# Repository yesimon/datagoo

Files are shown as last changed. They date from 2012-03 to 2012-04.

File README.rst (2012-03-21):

=======
Datagoo
=======

Project Description
===================

DataGoo is an open-source device designed to measure power generation
or consumption from small-scale electrical installations--cheaply. We
designed it to be initially deployed in `microhydro plants
<http://www.alterna-la.org/en/projects/microhydro>`_ run by `Alterna
<http://www.alterna-la.org/en>`_ in Guatemala.

DataGoo builds heavily on a similar, open-source device called the
`OpenEnergyMonitor <http://www.openenergymonitor.org>`_ (emon). The emon system
involves a transmitting device, a receiving device, and
display software and is targeted for in-home deployment. Our device is
designed for deployment in the field, so it uses a simpler output
interface: text messages over GSM and logging to an SD card.

Software Development
====================

Building with Arduino IDE
-------------------------

Download the required external libraries (see http://datagoo.readthedocs.org)
and place them in the Arduino ``libraries/`` directory. Open
``datagoo.ino``, compile and upload using the GUI.

Building With CMake
-------------------

**OS X/Linux**

To build on *nix systems (tested on OS X 10.7)::

   ./configure
   cd build
   make

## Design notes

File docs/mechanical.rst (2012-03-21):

.. _ref-mechanical:

==========
Mechanical
==========

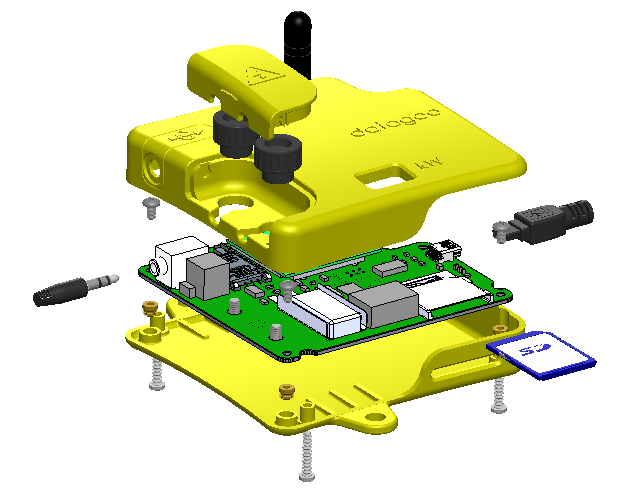
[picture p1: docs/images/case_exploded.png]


3D Printing the Datagoo Case
============================

The files below can be sent to any 3D printing company for
fabrication. I would suggest Shapeways, for price. Our first prototype
was completed by ZoomRP. Use these links to order your own copy:

| **Shapeways Permalinks**
| Upper Case: http://shpws.me/4lcv $33.74
| Lower Case: http://shpws.me/4lcx $37.51
| Cover: http://shpws.me/4ldY $6.22

The three files that constitute the case are the Cover, the Lower Body
and the Upper Body. The .stl (stereolithography) file is used by most
common 3d printing companies.

If there are needed changes to the solid files, the original
Solidworks files still exist. Please email nhallsny@stanford.edu with
any requests.

Known Errors
============

No known errors.

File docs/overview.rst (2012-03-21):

.. _ref-overview:

================
Project Overview
================

.. _ref-overview_mission:

Alterna's Mission
==================

Alterna on their mission:

   Alterna is a Center for Innovation and Entrepreneurship based in
   Quetzaltenango, Guatemala. Our mission is to develop technologies
   and build local businesses that satisfy basic needs and provide
   economic growth opportunities for the Guatemalan people in an
   environmentally sustainable way.

One of their major projects are micro-hydro plants in rural areas:

   Two million Guatemalans live without access to electricity. The vast
   majority of these people live in rural areas. Expansion of the
   national grid to the areas that are left unserved is increasingly
   difficult due to geographic constraints.

   Guatemala is also a country with great potential for utilization of
   hydroelectric power. The extensive rainfall and mountainous terrain of
   the country provide optimal conditions for generating electricity with
   water power.

| http://www.alterna-la.org/en
| http://www.alterna-la.org/en/projects/microhydro

Our Mission
============

Alterna currently has no good ways to monitor how much power these
micro-hydro plants produce, because off-the-shelf systems designed for
ultra-high current environments are expensive. Measuring power
generation is useful both to understand the efficacy of these
installations and because it is prerequisite to applying for carbon
grants which can offset the costs of development. Therefore, we
prototyped a circuit based on the open-source Arduino platform which
measures single-phase AC power coming out of the installation, logs it
to an SD card, and transmits daily SMS status updates over a GSM
network. The circuit can handle household voltages (~240V), currents
up to 100A, and costs around $200 (and as little as $100 when produced
at scale).

Carbon Offsets
---------------

Becoming accredited to sell carbon offsets is not a trivial process
and having information on kWh generated is only one part of it.
Nevertheless, organizations like `ClimateTrust
<http://www.climatetrust.org/>`_ exist to help organizations through
the bureaucratic steps of the process, but they can't do anything
without data, so we feel confident that this device will be an
important part of offsetting micro-hydro costs with carbon offsets.

The U.S. Department of Energy Clean Energy Application Center authored
a report on selling carbon offsets, which you can read `here
<http://www.chpcenternw.org/NwChpDocs/SellingCarbonOffsets.pdf>`_.

Specs In More Detail
---------------------

**Intended Purpose**

* Easy to use power measurement device
* Cheap to make
* Able to monitor current and voltage on 1 phase system
* Logs data to an SD card
* GSM connectivity provides two functionality:
* Sends an SMS if the voltage drops for an extended period
* Sends a daily "power collected" SMS with the power generated during
  that day
* Flexible design allows for reprogramming and hacking

**Intended Users**

* Engineering graduates and other workers with basic technology fluency.
* Designed so that it can be manufactured *relatively* easily.

**Power Measurement Specifications**

* Nominal voltage is 220V. Maximum we've seen was 225, minimum 219.
  There may be brief moments (around half a second or less) when it is
  much lower, down to 150V, when an extra heavy load is switched on.
* Nominal frequency is 60 Hz. Minimum 59, maximum 62.5.
* Single Phase AC.
* Current varies significantly depending on the season (water flow).
  Max in the rainy season is approximately 55A. Right now it's about
  30A. Dry season production may drop down as low as 15A, but we
  aren't sure on that yet.

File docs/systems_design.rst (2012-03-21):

.. _ref-systems_design:

==============
Systems Design
==============

Electrical Block Diagram
========================

Datagoo is built around the ATMEGA328P, the same processor used by many hobbyists for a variety of `Arduino <http://www.arduino.cc/>`_ designs. When coupled with an FTDI FT232RL USB-Serial circuit, the board can be programmed with any computer with a USB port. Other design decisions were made in the interest of cost and simplicty. Surface mount components were chosen for ease of manufacturing. The voltage and current measurement circuits were designed to utilize the ATMEGA328P's internal Analog-to-Digital converters, again reducing the component cost. The cell phone module was chosen for price - it is one of the cheapest GSM modules available. Also, all the components for which critical software needed to be written are avaiable in Arduino shield form, making testing custom applications more accessible.

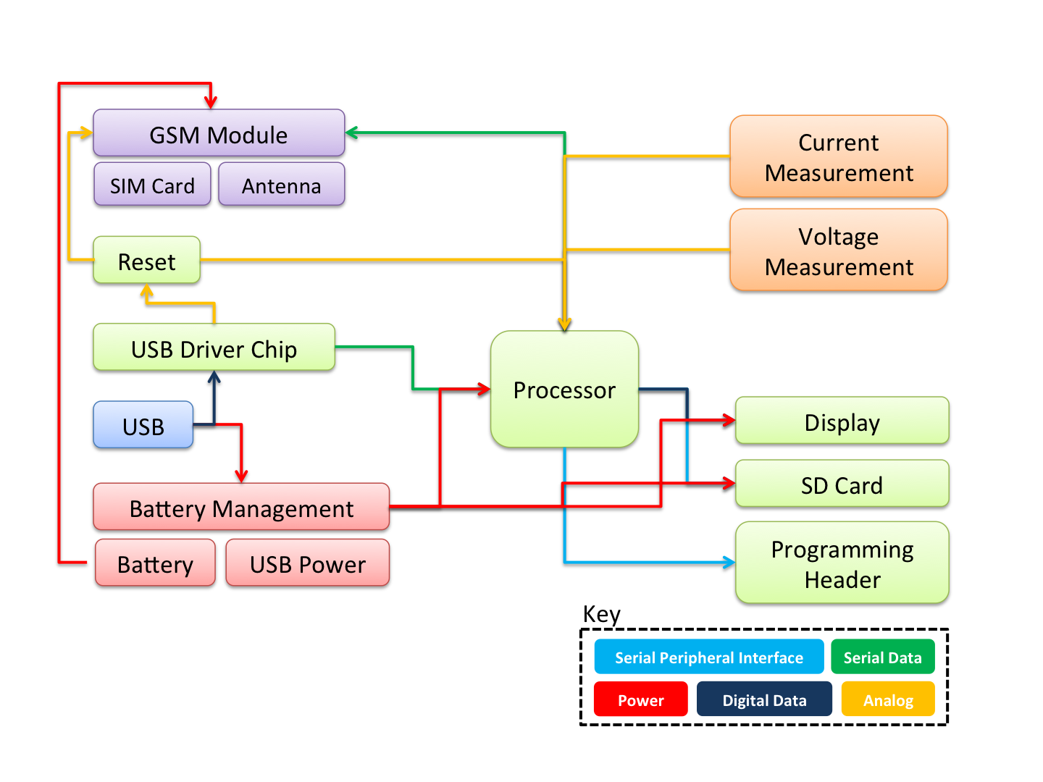
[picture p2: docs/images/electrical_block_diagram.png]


Component Locations
========================
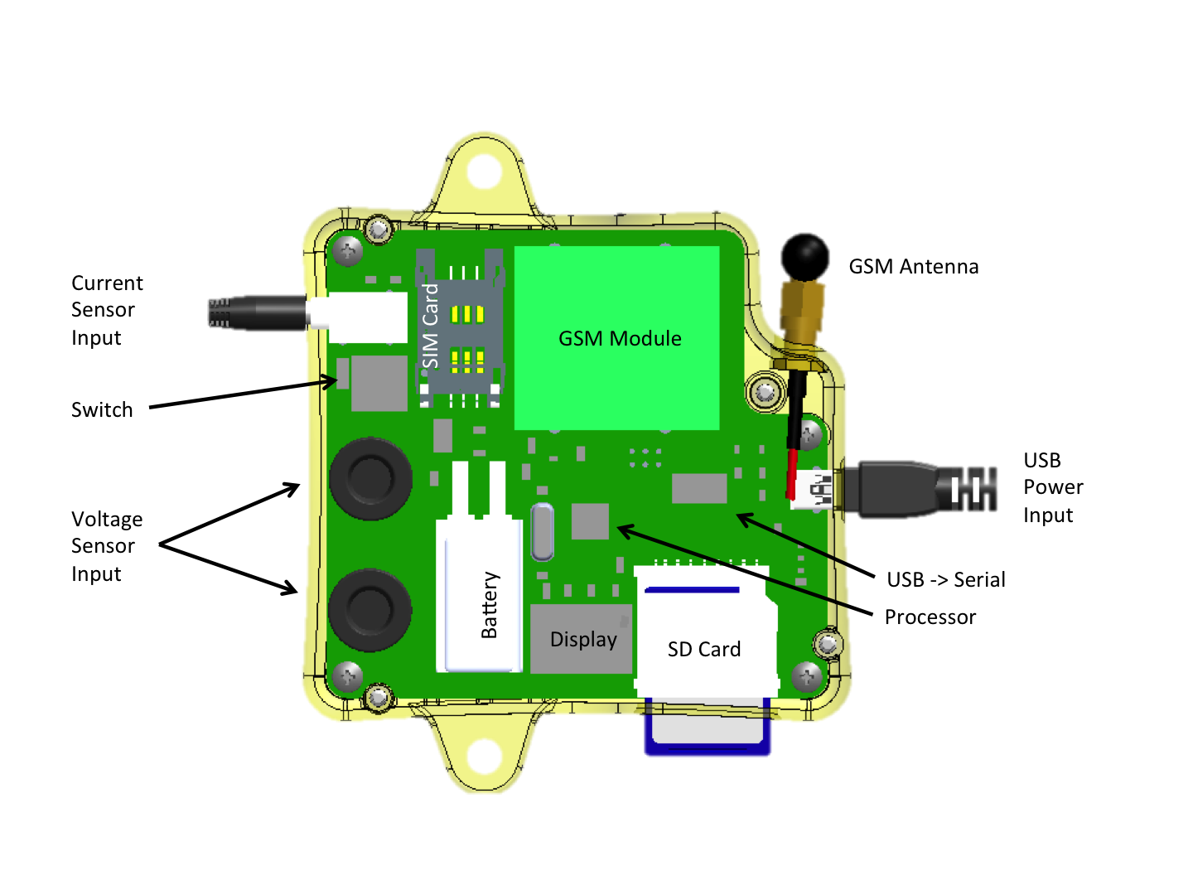
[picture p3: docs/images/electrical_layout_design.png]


Voltage Measurement System
==========================
The input voltage is rectified with a bridge rectifier. Then, a voltage divider reduces the voltage by a factor of 110. Then, the now 3.3V signal is run through an op-amp buffer for measurement accuracy. Finally, the signal is fed into the ATMEGA328P's Analog Input 1.

Current Measurement System
==========================
The Datagoo uses a "current transformer" to convert an AC signal into a readable value. A current transformer simply divides the current down. For our current transformer, a current of 100A will result in an output current of 33mA. The current is driven across a small resistor (33 ohms) to generate a voltage, which is then referenced against 1/2 * 3.3V, so both positive and negative currents can be sensed. The signal is then fed into the ATMEGA328P's Analog Input 0.

Battery Backup System
=====================
Datagoo uses a small lithium backup battery to keep the device on in the event of a power interruption. The battery is normally charged by the USB charger, and should be nominally at 4.2V. If the USB power is disconnected, the device switches to battery power and should last for ~30 minutes.

Display System
==============
The display is a two digit, seven segment display that is used to show the amount of kilo-Watts currently being measured by the device. The display is multiplexed - only one segment is on at a time, hence the faint flicker.

SMS Cell System
===============
A SM5100b GSM module is used to add cell network functionality to the Datagoo. Using the account information from a SIM card, it will send status text messages to the number written down in the configuration file. Since GSM network settings are specific to the country, make sure to change the right settings in the configuration file.

SD Card System
==============
The Datagoo is capable of reading and writing files to a SD card. This is used to log the amount of power generated as well as any faults. The user must edit a configuration file in order to use the unit.

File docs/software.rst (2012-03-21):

.. _ref-software:

========
Software
========

Downloading the Firmware
=========================

DataGoo's firmware is open-source and can be downloaded from GitHub:
https://github.com/yesimon/datagoo. Feel free to send a pull request
if you want to contribute changes either to the source code or the
documentation.

For write access to the repository, please contact Simon at
sye737+github@gmail.com.

Building with Arduino IDE
=========================

Download the required external libraries (see :ref:`libraries-label`)
and place them in the Arduino ``libraries/`` directory. Open
``datagoo.ino``, compile and upload using the GUI.

.. _libraries-label:

Software Libraries
==================

External Libraries
------------------

EmonLib
^^^^^^^^

A significant portion of our code is based on the OpenEnergyMonitor
project, which is building an open source energy monitoring solution
targeted at homes in the UK/Europe (and to a lesser extent the US).
Their library does much of the heavy lifting for us in converting the
raw voltage and current inputs coming into the DataGoo device into
power measurements.

We forked their code base primarily because we needed to output our
readings over GSM and to an SD logger, rather than over a custom
(low-power) RF system which OpenEMon uses to transmit their data.

| `Open Energy Monitor website <http://openenergymonitor.org/emon/>`_
| `GitHub (up-to-date code) for the library <https://github.com/openenergymonitor/EmonLib/>`_

Cell Phone Communication
-------------------------

There isn't exactly a library for communicating with the GSM module;
instead, it presents itself as a Serial device which can read and
write messages.

| `GSM Module Documentation <http://www.sparkfun.com/products/9533>`_
| In particular, see the `AT command set <http://www.sparkfun.com/datasheets/Cellular%20Modules/CEL-09533-AT%20Command_V1%5B1%5D.0.0-1.pdf>`_.

Also, see `this tutorial
<http://tronixstuff.wordpress.com/2011/01/19/tutorial-arduino-and-gsm-cellular-part-one/>`_
for some example code using the GSM module.

Standard Arduino Libraries
---------------------------

SD Library
^^^^^^^^^^^^

The library to write text to SD cards is part of the Arduino standard
library. It lets us write to the SD card just by creating a file and
then calling file.print().

`SD Library <http://arduino.cc/en/Reference/SD/>`_

SoftwareSerial Library
^^^^^^^^^^^^^^^^^^^^^^^

This library is also part of the Arduino standard library and emulates
a Serial port over software, which is especially critical for
interfacing with the GSM module (which takes input and provides output
over Serial).

`SoftwareSerial Library <http://arduino.cc/en/Reference/SoftwareSerial/>`_

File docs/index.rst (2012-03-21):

.. DataGoo documentation master file, created by
   sphinx-quickstart on Sun Mar  4 19:27:08 2012.
   You can adapt this file completely to your liking, but it should at least
   contain the root `toctree` directive.

Datagoo Documentation
=====================

Contents:

.. toctree::
   :maxdepth: 1

   quickstart
   overview
   ac_math
   systems_design
   components
   cost
   electrical
   mechanical
   software
   team

Project Description
===================

DataGoo is an open-source device designed to measure power generation
or consumption from small-scale electrical installations--cheaply. We
designed it to be initially deployed in `microhydro plants
<http://www.alterna-la.org/en/projects/microhydro>`_ run by `Alterna
<http://www.alterna-la.org/en>`_ in Guatemala.

DataGoo builds heavily on a similar, open-source device called the
`OpenEnergyMonitor <http://www.openenergymonitor.org>`_ (emon). The emon system
involves a transmitting device, a receiving device, and
display software and is targeted for in-home deployment. Our device is
designed for deployment in the field, so it uses a simpler output
interface: text messages over GSM and logging to an SD card.

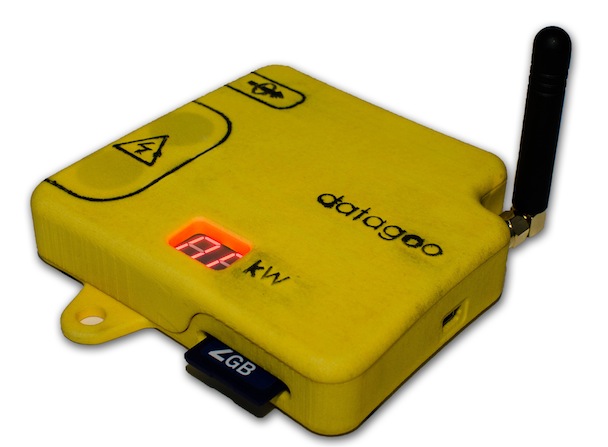
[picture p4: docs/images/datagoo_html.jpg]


Indices and tables
==================

* :ref:`genindex`
* :ref:`search`

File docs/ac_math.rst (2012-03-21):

.. _ref-ac_math:

========================
Power Measurement Theory
========================

This page covers the mathematics behind calculating real power,
apparent power, power factor, RMS voltage and RMS current from
instantaneous Voltage and Current measurements of single phase AC
electricity. Discrete time equations are detailed since the
calculations are carried out in the Arduino in the digital
domain. There are also code snippets of the equations included below:

**Real Power**

Real power (also known as active power) is defined as the
power used by a device to produce useful work.

Mathematically it is the definite integral of voltage, :math:`u(t)`,
times current, :math:`i(t)`, as follows:

.. math::

   P = \frac{1}{T} \int u(n)\times i(n) \, \mathrm{d}t

**Equation 1. Real Power Definition.**

:math:`U` - Root-Mean-Square (RMS) voltage.

:math:`I` - Root-Mean-Square (RMS) current.

:math:`cos(\varphi)` - Power factor.

The discrete time equivalent is:

.. math::

   P = \frac{1}{T} \sum_{n=0}^{N-1} u(n)\times i(n)

**Equation 2. Real Power Definition in Discrete Time.**

:math:`u(n)` - sampled instance of :math:`u(t)`

:math:`i(n)` - sampled instance of :math:`i(t)`

:math:`N` - number of samples.

Real power is calculated simply as the average of N voltage-current
products. It can be shown that this method is valid for both
sinusoidal and distorted waveforms.

Code example of equation 2::

   for (n=0; n < numberOfSamples; n++)
   {
       //instV and instI calculation from raw ADC input goes here.
       instP = instV * instI;
       sumP += instP;
   }
   realPower = sumP / numberOfSamples;

**RMS Voltage and Current Measurement**

An RMS value is defined as the square root of the mean value of the
squares of the instantaneous values of a periodically varying
quantity, averaged over one complete cycle. The discrete time equation
for calculating voltage RMS is as follows:

.. math::

   U_{rms} = \sqrt{\frac{\sum_{n=0}^{N-1} u^2(n)}{N}}

Equation 3. Voltage RMS Calculation in Discrete Time Domain.

Current RMS is calculated using the same equation, only substituting
voltage samples, :math:`u(n)`, for current samples, :math:`i(n)`.

Code example of equation 3::

   for (n=0; n < numberOfSamples; n++)
   {
       //instV calculation fsqV = instV * instV;
       sumV += sqV;
   }
   Vrms = sqrt(sumV / numberOfSamples);

Substitute V for I for current.

**Apparent Power and Power Factor**

.. math::

   P_{apparent} = V_{rms} \times I_{rms}

   cos(\varphi) = \frac{P_{real}}{P_{apparent}}

**Bringing it all together**

The following snippet carries out all the measurements above::

   for (n=0; n < numberOfSamples; n++)
   {
       //instV and instI calculation from raw ADC input goes here.
       sqV = instV * instV;
       sumV += sqV;
       sqI = instI * instI;
       sumI += sqI;
       instP = instV * instI;
       sumP +=instP;
   }
   Vrms = sqrt(sumV / numberOfSamples);
   Irms = sqrt(sumI / numberOfSamples);
   realPower = sumP / numberOfSamples;
   apparentPower = Vrms * Irms;
   powerFactor = realPower / apparentPower;

Thats it, thats the core of single phase AC power measurment
calculation.

This page is based on Atmel's AVR465 Application Note pp. 12-15 which can be
found `here <http://www.atmel.com/dyn/resources/prod_documents/doc2566.pdf>`_.

Page referenced from `OpenEnergyMonitor <http://openenergymonitor.org/emon/buildingblocks/ac-power-the-maths>`_.

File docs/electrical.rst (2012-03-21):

.. _ref-electrical:

==========
Electrical
==========

.. warning::

   Before trying to have the PCB manufactured, please contact
   nhallsny@stanford.edu for the correct settings. For components and
   designators, check out the Bill of Materials

..
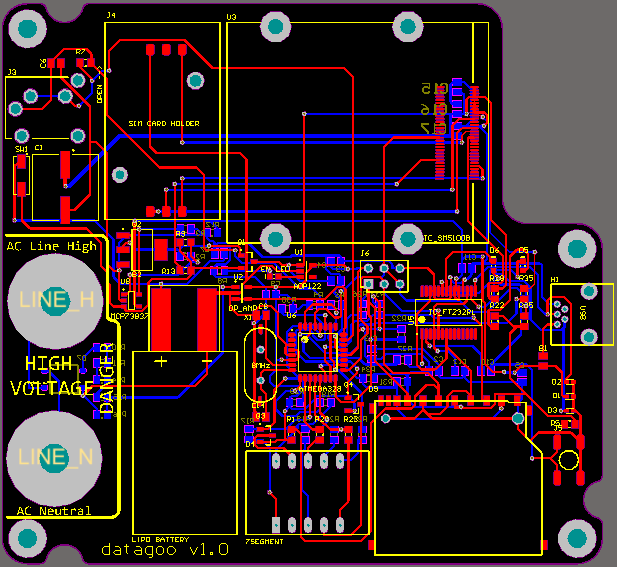
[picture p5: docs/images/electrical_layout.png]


Description
===========

For a description of how each sub-system works, consult the Systems Design

Schematic
=========

.. note::

   See below for known bugs before using these designs.

:download:`Download Electrical Schematic <images/electrical_schematic.pdf>`.

Electrical Schematics (generated in Altium):

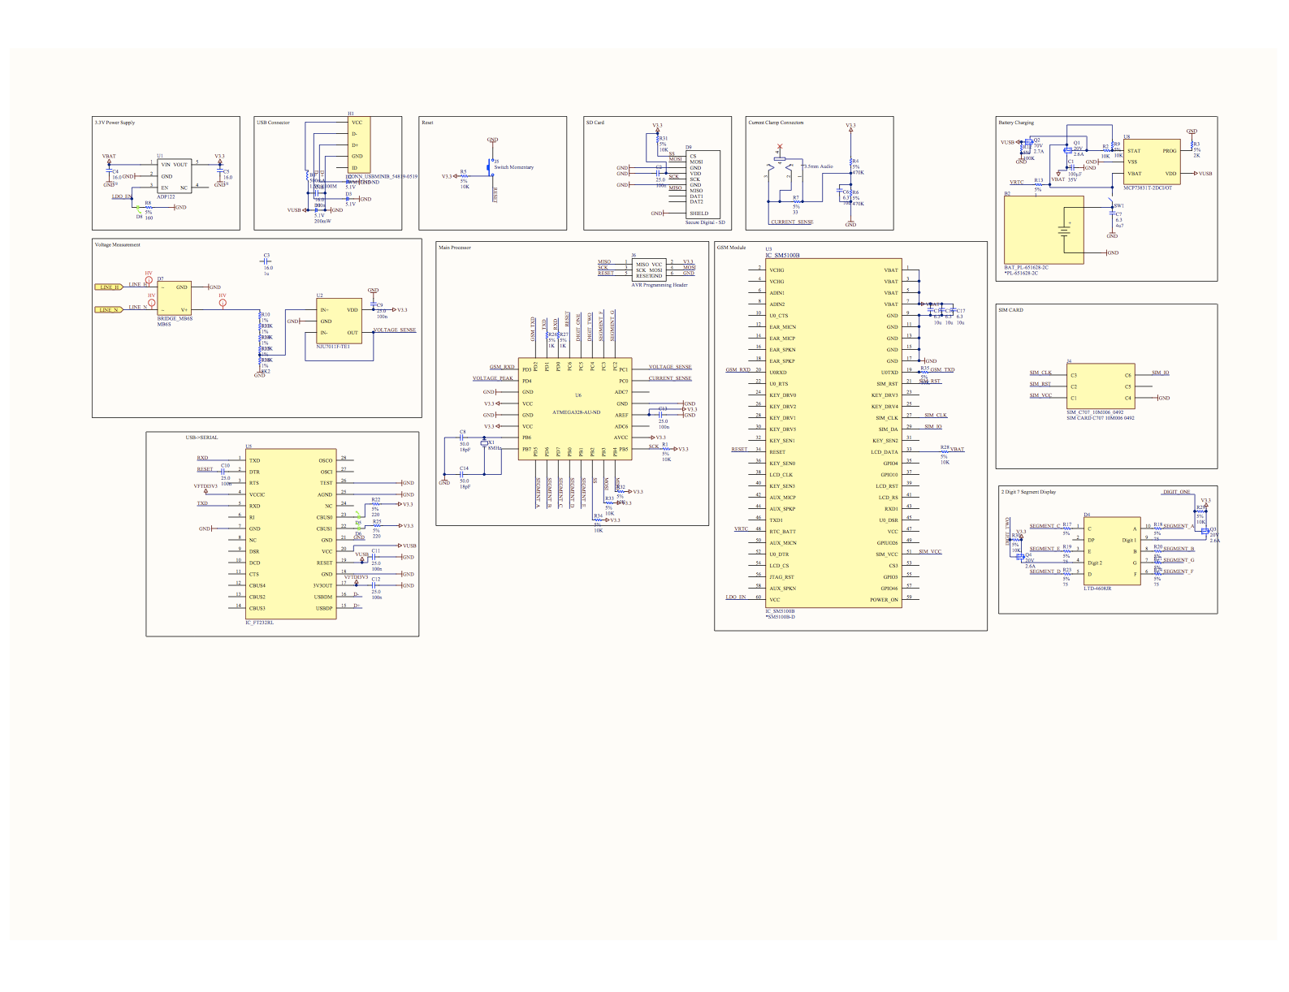
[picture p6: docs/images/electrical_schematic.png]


Design Errors
=============

1. If the device is completely discharged, and is recharged with a USB
   charger, the reset button needs to be pressed in order to reset the
   device.
2. The voltage measurement is not isolated. While we made this
   decision for cost reasons, for safety and ease of hacking the
   design should be updated with an isolation transformer.

Schematic Errors
================

There are no known errors in the below schematic.

Layout Errors
=============

There are several known errors in the layout:

1. The LDO_EN is not connected from the GSM Module
2. The GSM_TXD is not connected to the GSM Module
3. The MOSI pin on the AVR programming header is RST, and should be MOSI
4. The Zener diode footprint does not have a direction indicator
5. The LED footprint does not have a clear direction indicator
6. The footprint for SW1 is incorrect, but hackable
7. The large 100uF capacitor doesn't have a polarity marking
8. The same net is connected to two of the seven segment display pins
9. The pullup for the reset net is not connected to 3.3V

3D Layout
=========

The 3D render of the electrical layout:

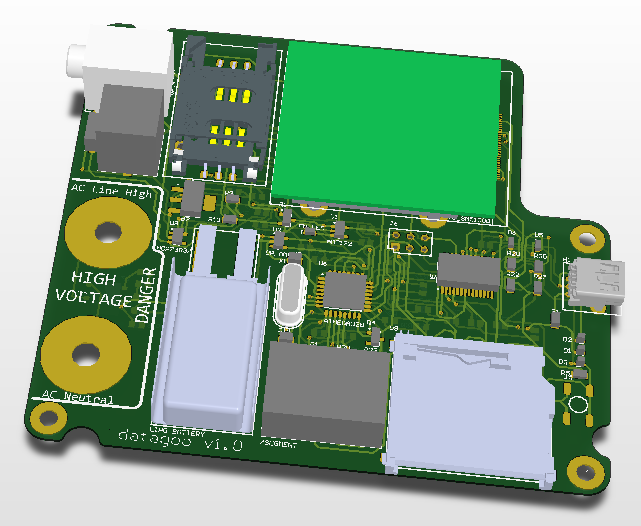
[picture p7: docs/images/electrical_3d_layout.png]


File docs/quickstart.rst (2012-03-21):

.. _ref-quickstart:

================
Quickstart Guide
================

This guide is for installing a datagoo with hardware and firmware
preinstalled. It details the steps for configuring and attaching the
datagoo to a power supply, so that it is ready to send text
notifications.

Required Materials
==================
* Datagoo
* Current clamp
* Small philips screwdriver
* USB mini-b charger
* Activated SIM card with SMS plan (minimum 50 SMS per month)
* SD Card (minimum 16 MB)
* AC measurement cord
* Screws for mounting

Installation
============

.. warning::

   Make sure that all wires are disconnected from the device before removing the cover.

#. Remove the high voltage cover (may require a small tool) and the
   two plastic knobs.

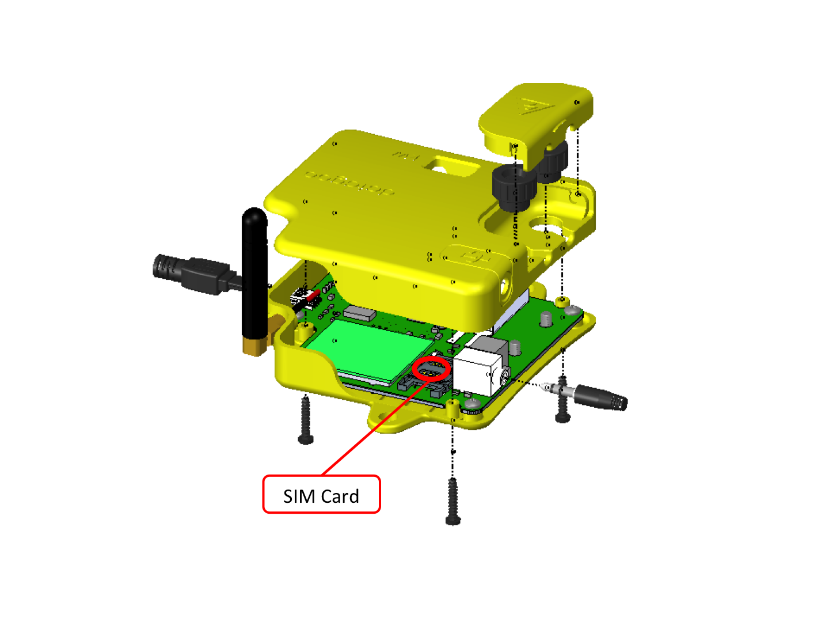
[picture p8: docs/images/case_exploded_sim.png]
   

#. Unscrew the four screws on the bottom of the device and remove the
   top case.

#. Place an activated SIM card in the SIM card holder. (Make sure that
   the SIM card is capable of sending text messages via a normal
   mobile phone before trying with the Datagoo)

#. Flip the ON/OFF switch to ON. You should see a small green light turn on.

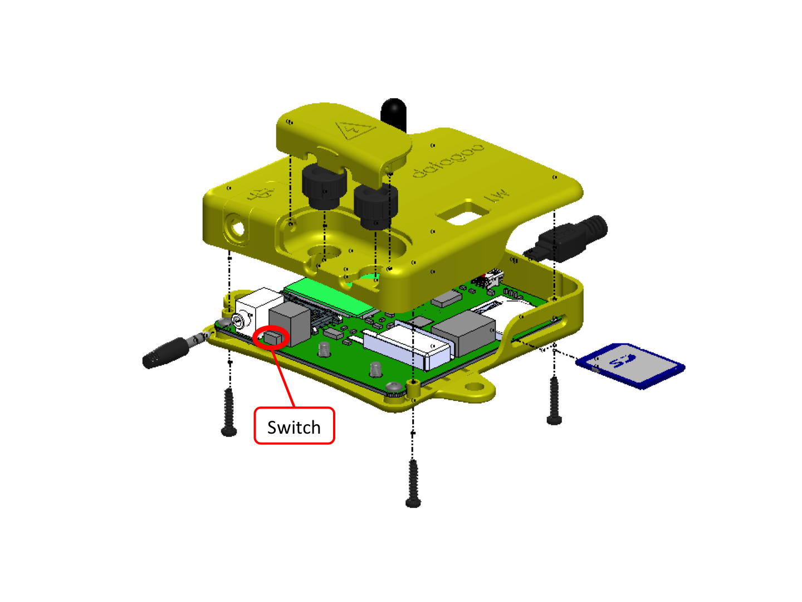
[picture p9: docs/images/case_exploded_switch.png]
   

#. Put the top back on the device and screw in the four screws. Do not
   put knobs or high voltage cover back on.

#. Format an SD card to FAT16. (This is by default for SD cards, but
   please double check).

#. Create file ``CELL.TXT`` containing the mobile number to notify of
   power usage statistics and alerts. An example ``CELL.TXT`` file::

      5731921102

#. Place the SD card in the SD slot.

#. Plug in USB charger.

   .. warning::

      The USB charger should not be a computer. Plugging in the
      computer USB charger and line voltage to the voltage terminals
      at the same time will destroy both the datagoo and your
      computer.

#. Connect current sensor. The current sensor should be clamped around
   only one wire.

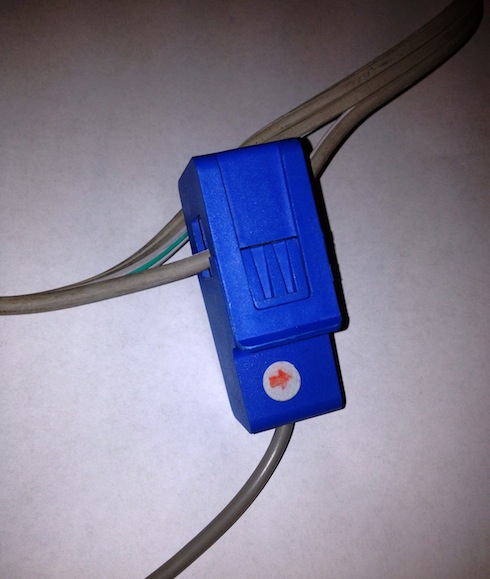
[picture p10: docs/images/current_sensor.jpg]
   

   .. warning::

      Use extreme caution when working with high voltages. Stripping
      and connecting a live (plugged in) wire may cause electrocution
      to the user.

#. Strip two wires for the AC voltage signal. Make sure it is not
   plugged in!

#. Place one wire around the upper screw and screw down the plastic
   knob. Place the other wire on the lower screw and screw down the
   plastic knob. Give both wires a quick tug to make sure they are
   attached properly.

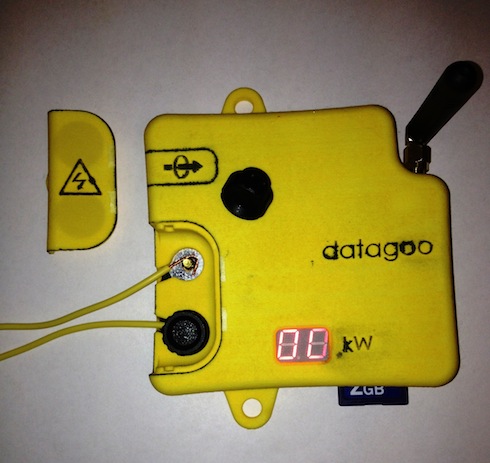
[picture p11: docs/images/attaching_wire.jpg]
   

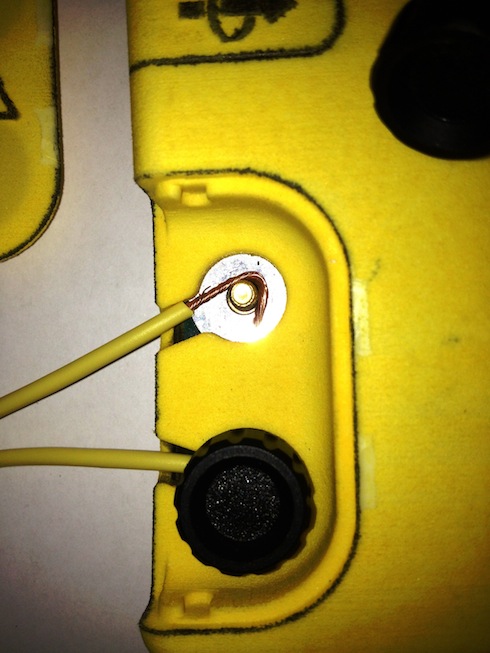
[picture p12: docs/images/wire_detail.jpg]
   

#. Replace the high voltage cover.

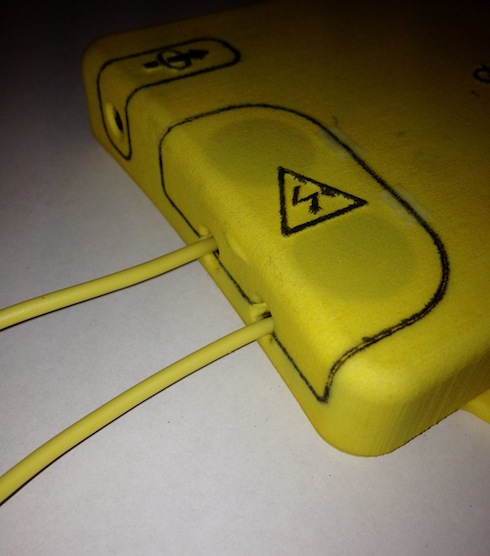
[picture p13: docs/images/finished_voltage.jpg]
   

#. Plug the other end of the voltage wires to the power source.

#. The red display shows the number of kW currently being generated.

#. You're ready to go!

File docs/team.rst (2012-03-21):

.. _ref-team:

====
Team
====

Nathan - nhallsny@stanford.edu

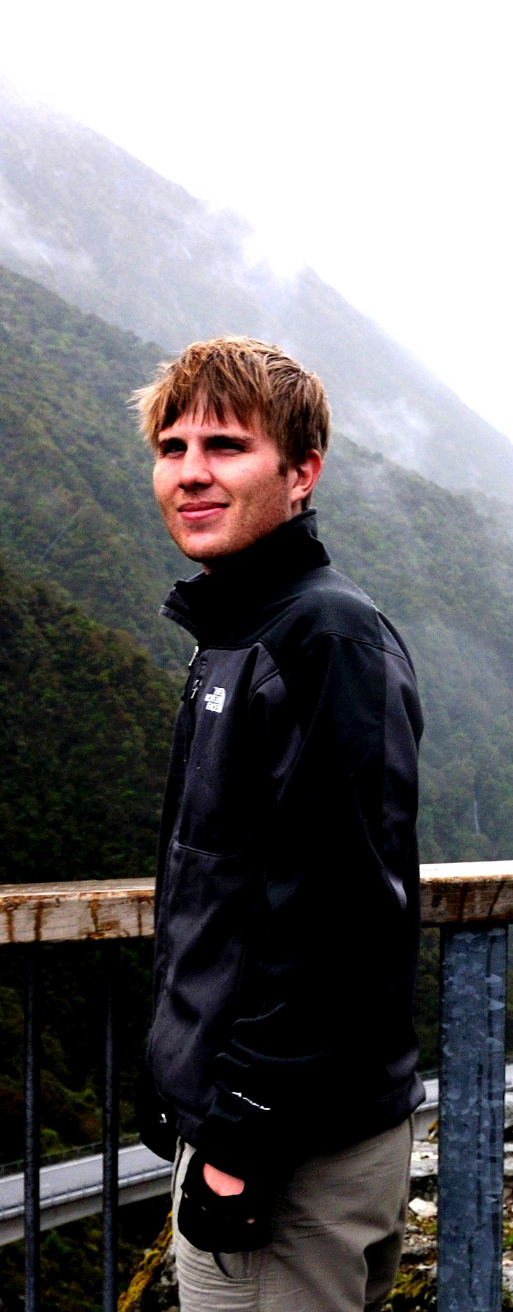
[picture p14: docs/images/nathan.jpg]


Ravi - sankarr@stanford.edu

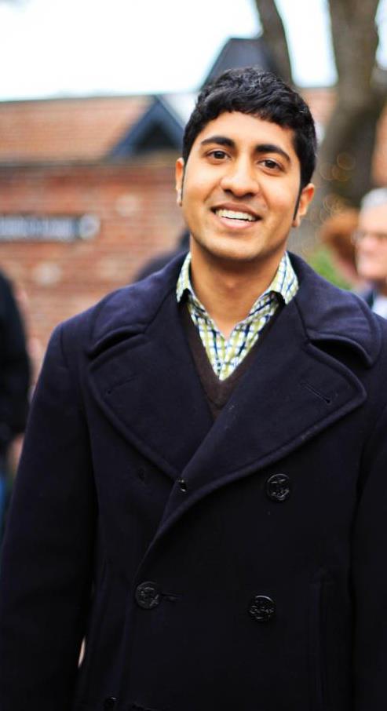
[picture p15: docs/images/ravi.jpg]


Simon - sye@stanford.edu

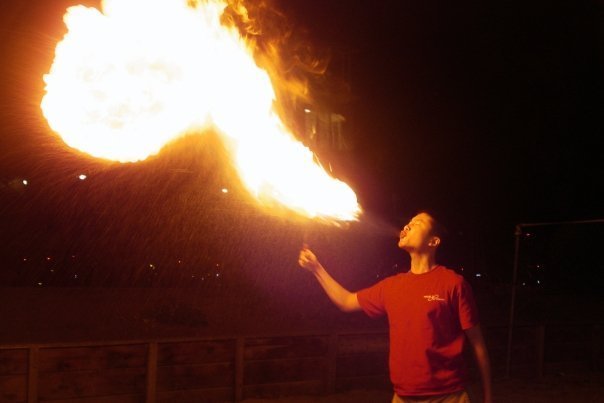
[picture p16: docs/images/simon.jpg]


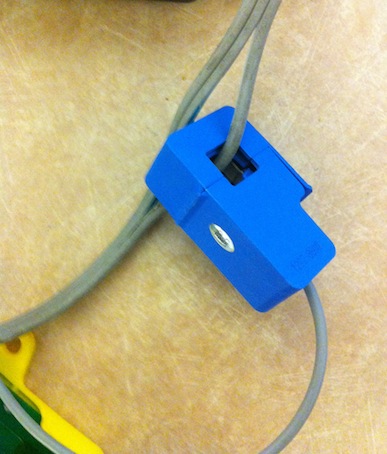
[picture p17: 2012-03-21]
docs/images/attached_ct.jpg

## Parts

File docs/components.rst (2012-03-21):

.. _ref-components:

==========
Parts List
==========

We chose to purchase components from a number of suppliers:

* GSM Module and Antenna: `Sparkfun <http://www.sparkfun.com/>`_
* PCB: `Sierra ProtoExpress <http://www.protoexpress.com/>`_
* Electrical Componentss: `Digikey <http://www.digikey.com/>`_
* Battery: `Batteryspace <http://www.batteryspace.com/>`_
* 3D Printing: `Shapeways <http://www.shapeways.com/>`_
* Mechanical Components: `McMaster-Carr Supply <http://www.mcmaster.com/>`_
* Current Clamp: `EpicTinker <http://www.epictinker.com/>`_

Common components, such as a USB charger and hacked AC cable, were not
purchased but salvaged.

Bill of Materials
=================

.. tabularcolumns:: |p{3cm}|p{1cm}|p{4.5cm}|p{0.75cm}|p{1.5cm}|p{3cm}|
.. list-table::
   :widths: 20 5 15 5 10 15
   :header-rows: 1

   * - Description
     - Designator
     - Library Part Name
     - Quantity
     - Supplier
     - Part Number
   * - MOSFET N-CH 70V 3.8A SOT-223
     - Q2
     - NFET_ZXMN7A11GCT
     - 1
     - Digikey
     - ZXMN7A11GCT-ND
   * - CONN USB RECEPTACLE 5POS RT ANG
     - H1
     - CONN_USBMINIB_54819-0519
     - 1
     - Digikey
     - WM17115-ND
   * - RES 110K OHM 1/8W 1% 0805 SMD
     - R10, R11, R14, R15
     - RHM110KCRCT-ND
     - 4
     - Digikey
     - RHM110KCRCT-ND
   * - RES 33 OHM 1/10W 3900PPM 5% 0805
     - R7
     - P33CECT-ND
     - 1
     - Digikey
     - P33CECT-ND
   * - RES 10K OHM 1/10W 1500PPM 5%0805
     - R1, R2, R5, R9, R28, R29, R30, R31, R32, R33, R34, R35
     - P10KCBCT-ND
     - 12
     - Digikey
     - P10KCBCT-ND
   * - IC OPAMP CMOS LOW-PWR MTP5
     - U2
     - OP_NJU7011F-TE1
     - 1
     - Digikey
     - NJU7011F-TE1CT-ND
   * - DIODE ZENER 5.1V 200MW SOD-523F
     - D1, D2, D3
     - ZENER_MM5Z5V1
     - 3
     - Digikey
     - MM5Z5V1CT-ND
   * - IC CONTROLLR LI-ION 4.2V SOT23-5
     - U8
     - LIION_MCP73837/8
     - 1
     - Digikey
     - MCP73831T-2DCI/OTCT-ND
   * - IC RECT BRIDGE 0.5A 600V 4SOIC
     - D7
     - BRIDGE_MB6S
     - 1
     - Digikey
     - MB6SCT-ND
   * - MOSFET P-CH 20V 2.6A SOT23
     - Q1, Q3, Q4
     - PFET_IRLML2246TRPBF
     - 3
     - Digikey
     - IRLML2246TRPBFCT-ND
   * - SWITCH DIP LOW PRO 1 POS GOLD
     - SW1
     - SWITCH_KAJ01SGGT
     - 1
     - Digikey
     - EG4416-ND
   * - 3.5mm Audio Jack
     - J3
     - 3.5mm Audio
     - 1
     - Digikey
     - CP1-3533NS-ND
   * - IC MCU AVR 32K FLASH 32TQFP
     - U6
     - MCU_ATMEGA328
     - 1
     - Digikey
     - ATMEGA328-AU-ND
   * - 3.3v LDO up to 300 mA
     - U1
     - ADP122
     - 1
     - Digikey
     - ADP122AUJZ-3.3-R7CT-ND
   * - CONN SD CARD PUSH-PULL SMD
     - D9
     - SDCARD_2041021-4
     - 1
     - Digikey
     - A101492CT-ND
   * - 8MHz  18pF 10ppm
     - X1
     - XTAL_8MHz-49US
     - 1
     - Digikey
     - 887-1233-ND
   * - RES 1.0K OHM 1/8W 5% 0805 SMD
     - R26, R27
     - 541-1.0KACT-ND
     - 2
     - Digikey
     - 541-1.0KACT-ND
   * - CAP ALUM 100UF 35V 20% SMD
     - C1
     - AUTO_CAP_ALUM_100UF_35V_20%_SMD
     - 1
     - Digikey
     - 493-4471-1-ND
   * - CAP CER 1UF 16V 10% X7R 0805
     - C3, C4, C5
     - CAP CER 1UF 16V 10% X7R 0805
     - 3
     - Digikey
     - 490-1691-1-ND
   * - CAP CER 0.1UF 25V 10% X7R 0805
     - C2, C9, C10, C11, C12, C13
     - CAP CER 0.1UF 25V 10% X7R 0805
     - 6
     - Digikey
     - 478-3755-1-ND
   * - CAP CER 10UF 6.3V 10% X5R 0805
     - C6, C15, C16, C17
     - CAP CER 10UF 6.3V 10% X5R 0805
     - 4
     - Digikey
     - 478-1417-1-ND
   * - CAP CER 4.7UF 6.3V 10% X5R 0805
     - C7
     - CAP CER 4.7UF 6.3V 10% X5R 0805
     - 1
     - Digikey
     - 478-1416-1-ND
   * - CAP CER 18PF 50V 5% NP0 0805
     - C8, C14
     - CAP CER 18PF 50V 5% NP0 0805
     - 2
     - Digikey
     - 478-1307-1-ND
   * - LED CHIPLED 570NM GREEN 0603 SMD
     - D5, D6, D8
     - LED_LG Q971-KN-1
     - 3
     - Digikey
     - 475-1409-1-ND
   * - FERRITE CHIP 1500 OHM 500MA 0805
     - B1
     - FB_MMZ2012Y152B
     - 1
     - Digikey
     - 445-1560-1-ND
   * -
     - C5
     - CAP CER 0.1UF 16V 10% X7R 0805
     - 1
     - Digikey
     - 399-1167-1-ND
   * - CONN SMCARD SIMLOCK W/ALIGN PINS
     - J4
     - SIM_C707_10M006_0492
     - 1
     - Digikey
     - 361-1021-1-ND
   * - RES 470K OHM 1/8W 5% 0805 SMD
     - R4, R6
     - 311-470KARCT-ND
     - 2
     - Digikey
     - 311-470KARCT-ND
   * - RES 220 OHM 1/8W 5% 0805 SMD
     - R22, R25
     - 311-220ARCT-ND
     - 2
     - Digikey
     - 311-220ARCT-ND
   * - RES 160 OHM 1/8W 5% 0805 SMD
     - R8
     - 311-160ARCT-ND
     - 1
     - Digikey
     - 311-160ARCT-ND
   * - RES 100K OHM 1/8W 5% 0805 SMD
     - R12
     - 311-100KARCT-ND
     - 1
     - Digikey
     - 311-100KARCT-ND
   * - RES 75 OHM 1/8W 5% 0805 SMD
     - R17, R18, R19, R20, R21, R23, R24
     - 311-75ARCT-ND
     - 7
     - Digikey
     - 311-75ARCT-ND
   * - RES 8.20K OHM 1/8W 1% 0805 SMD
     - R16
     - 311-8.20KCRCT-ND
     - 1
     - Digikey
     - 311-8.20KCRCT-ND
   * - RES 2.0K OHM 1/8W 5% 0805 SMD
     - R3
     - 311-2.0KARCT-ND
     - 1
     - Digikey
     - 311-2.0KARCT-ND
   * - RES 1.0 OHM 1/8W 5% 0805 SMD
     - R13
     - 311-1.0ARCT-ND
     - 1
     - Digikey
     - 311-1.0ARCT-ND
   * - LED 7-SEG .40 2DGT SUPER RED CA
     - D4
     - 7SEG_2DIG_LTD-4608JR
     - 1
     - Digikey
     - 160-1538-5-ND
   * - IC USB FS SERIAL UART 28-SSOP
     - U3
     - USB->SERIAL
     - 1
     - Digikey
     - 768-1007-1-N
   * - Polymer Li-Ion Cell:3.7V 210mAh
     - J5
     - LITHIUM_BATTERY
     -
     - Batteryspace
     - PL-651628-2C
   * - Quad-band cellular antenna
     -
     -
     - 1
     - Sparkfun
     - CEL-00675
   * - SM5100B-D GSM/GPRS Module
     - J6
     - GSM MODULE
     -
     - Sparkfun
     - CEL-09533
   * - AVR Programming Header
     - None
     - CONN HEADER 6POS .100 STR 15A
     - 1
     - Digikey
     - 609-3210-ND
   * - 3D Printed Case Upper
     - None
     -
     - 1
     - Shapeways
     - N/A
   * - 3D Printed Case Lower
     - None
     -
     - 1
     - Shapeways
     - N/A
   * - 3D Printed Case High Voltage Cover
     - None
     -
     - 1
     - Shapeways
     - N/A
   * - USB Charger
     - None
     -
     - 1
     - Any Supplier
     -
   * - Power Cable
     - None
     -
     - 1
     - Dumpster
     -
   * - Tri-P Phillips Thread-Forming Screw for Plastic, Black-Finish
       Zinc-Plated Steel, 4-20
     - None
     -
     - 4
     - Mcmaster-Carr
     - 92295A106
   * - Metric Nylon Fluted-Rim Knob, M4 X .7 Threaded Insert, 16 mm
       Diameter
     - None
     -
     - 2
     - Mcmaster-Carr
     - 62935K15
   * - Metric Pan Head Phillips Machine Screw, Zinc-Plated Steel, M3
       Size, 5MM Length, .5MM Pitch
     - None
     -
     - 4
     - Mcmaster-Carr
     - 92005A114
   * - Metric Brass Pan Head Slotted Machine Screw, M4 Size, 6MM
       Length, 0.7MM Pitch, Packs of 25
     - None
     -
     - 2
     - Mcmaster-Carr
     - 90928A327
   * - Metric Brass Threaded Insert for Thermoplastc, Tapered, M3-.5
       Internal Thread, 3.8MM Length
     - None
     -
     - 4
     - Mcmaster-Carr
     - 94180A331
   * - Current Clamp
     - None
     -
     - 1
     - Epictinker
     - SCT-013

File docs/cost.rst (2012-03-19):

.. _ref-cost:

==============
Cost Estimates
==============

This page contains volume cost estimates for making more Datagoo Power
Loggers:

====================  ====   ====   =====   =====  ==================================================
Item                  1      10     50      100    Comments
====================  ====   ====   =====   =====  ==================================================
PCB                   $33    $24    $7.74   $4.50  Based on Sierra Protoexpress
Case                  $82    $82    $82     $4     Tooling Required
Electronics           $50    $50    $35     $30
GSM Module + Antenna  $60    $60    $60     $60    It's likely that a lower price could be negotiated
Current Clamp         $11    $11    $11     $5     The 100 is a guestimate
Assembly              $0     $10    $5      $2     Again, estimates

Total                 $236   $227   $196    $104
====================  ====   ====   =====   =====  ==================================================

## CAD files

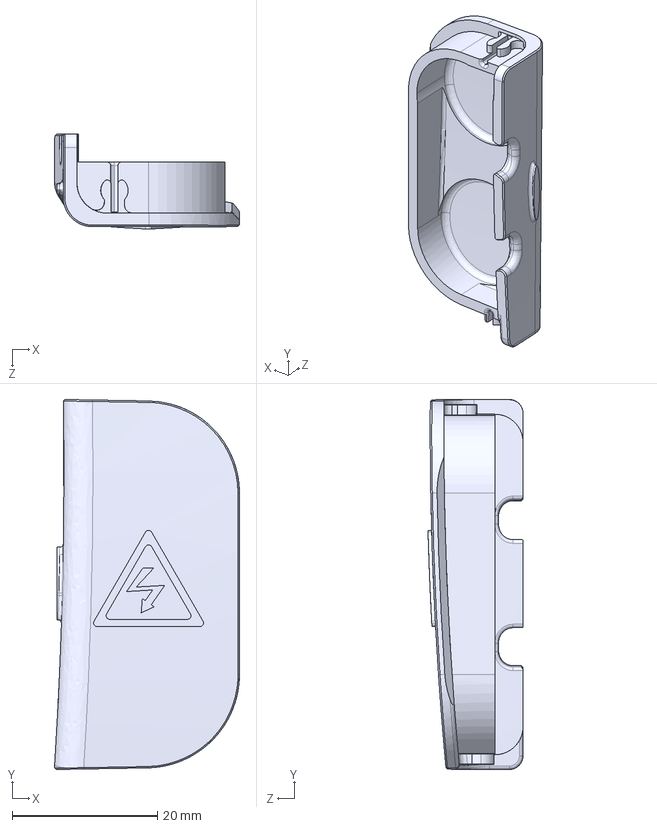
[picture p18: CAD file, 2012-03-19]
hardware/mechanical/Cover.STEP
25.5 x 51.0 x 13.1 mm

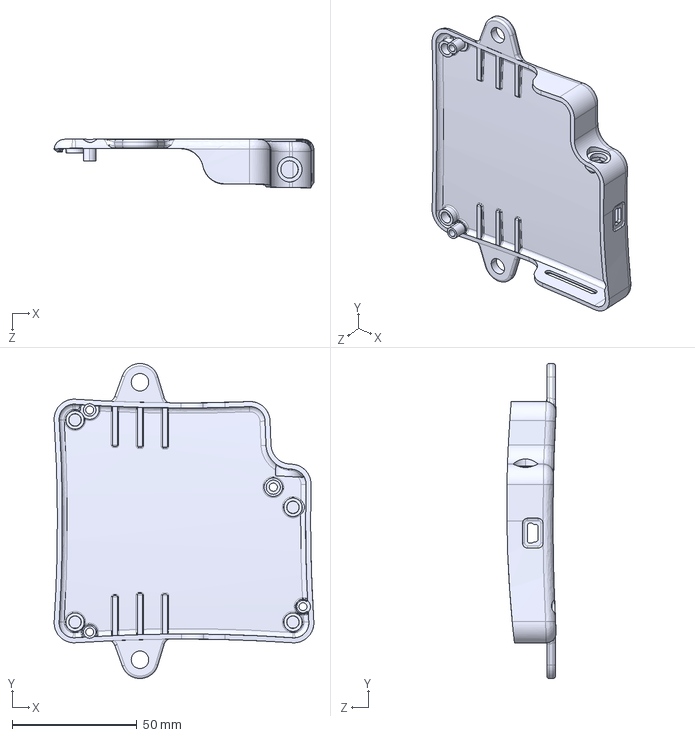
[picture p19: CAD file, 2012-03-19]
hardware/mechanical/Lower Body.STEP
104.0 x 126.1 x 19.7 mm

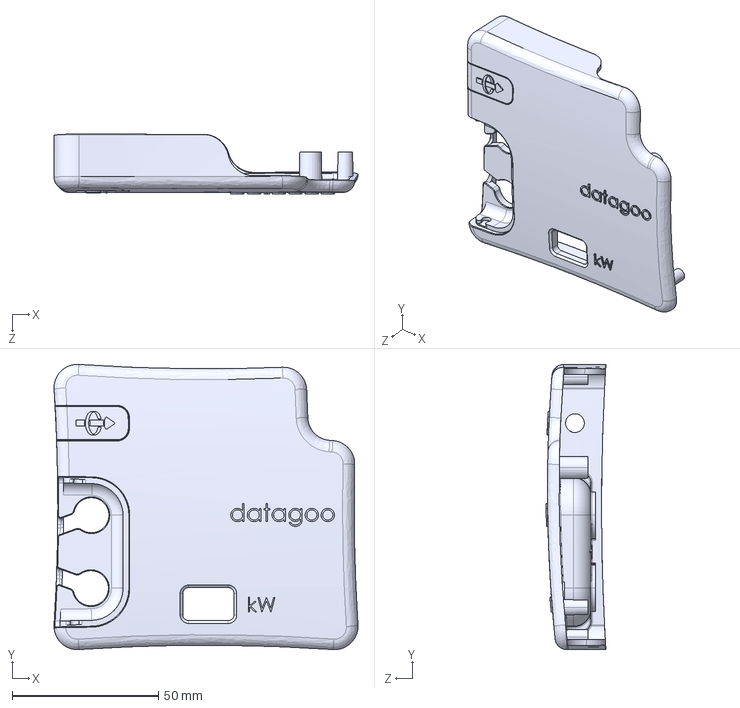
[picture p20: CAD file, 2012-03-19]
hardware/mechanical/Upper Body.STEP
104.0 x 97.5 x 20.5 mm

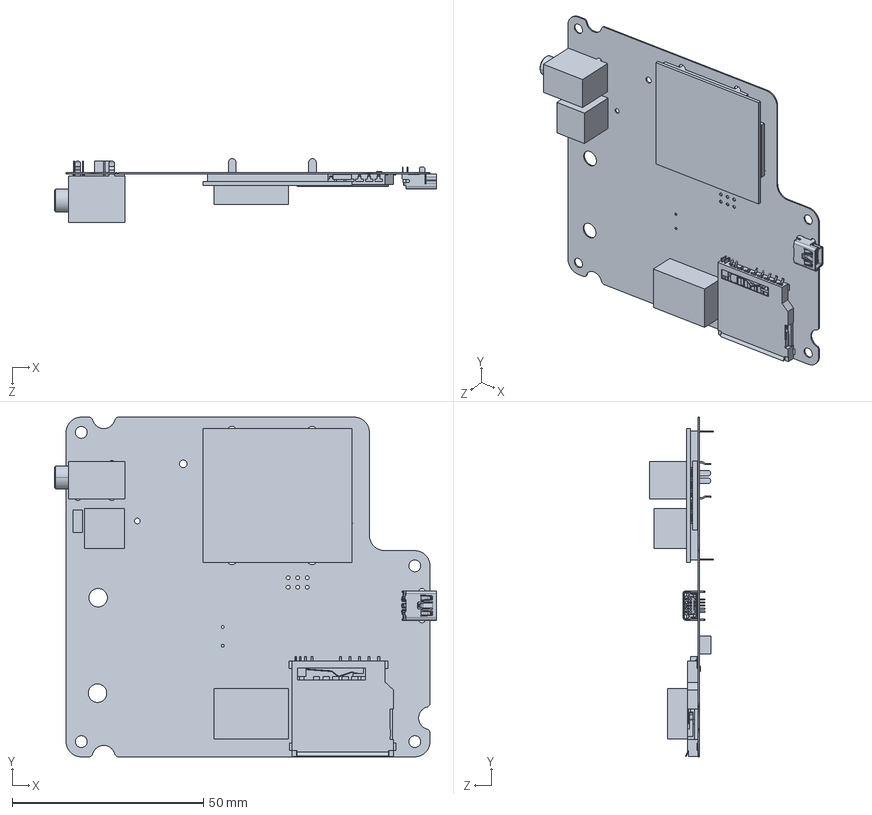
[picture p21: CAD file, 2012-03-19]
hardware/mechanical/PCBA_4.STEP
99.9 x 88.9 x 16.7 mm

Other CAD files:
hardware/mechanical/Cover.STL
hardware/mechanical/Lower Body.STL
hardware/mechanical/Upper Body.STL

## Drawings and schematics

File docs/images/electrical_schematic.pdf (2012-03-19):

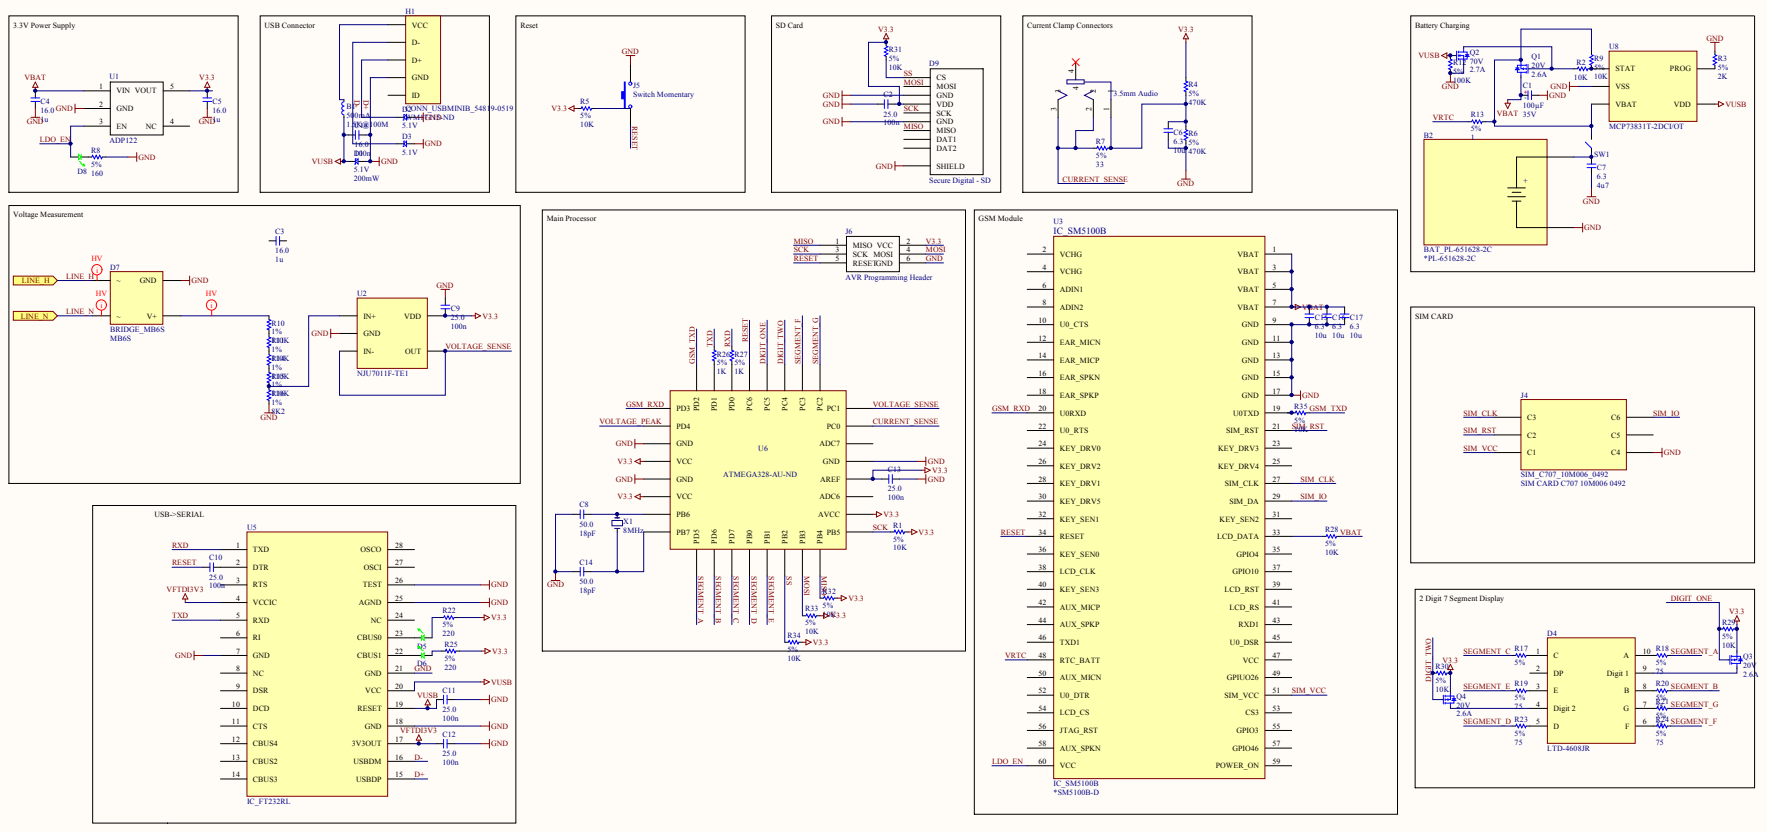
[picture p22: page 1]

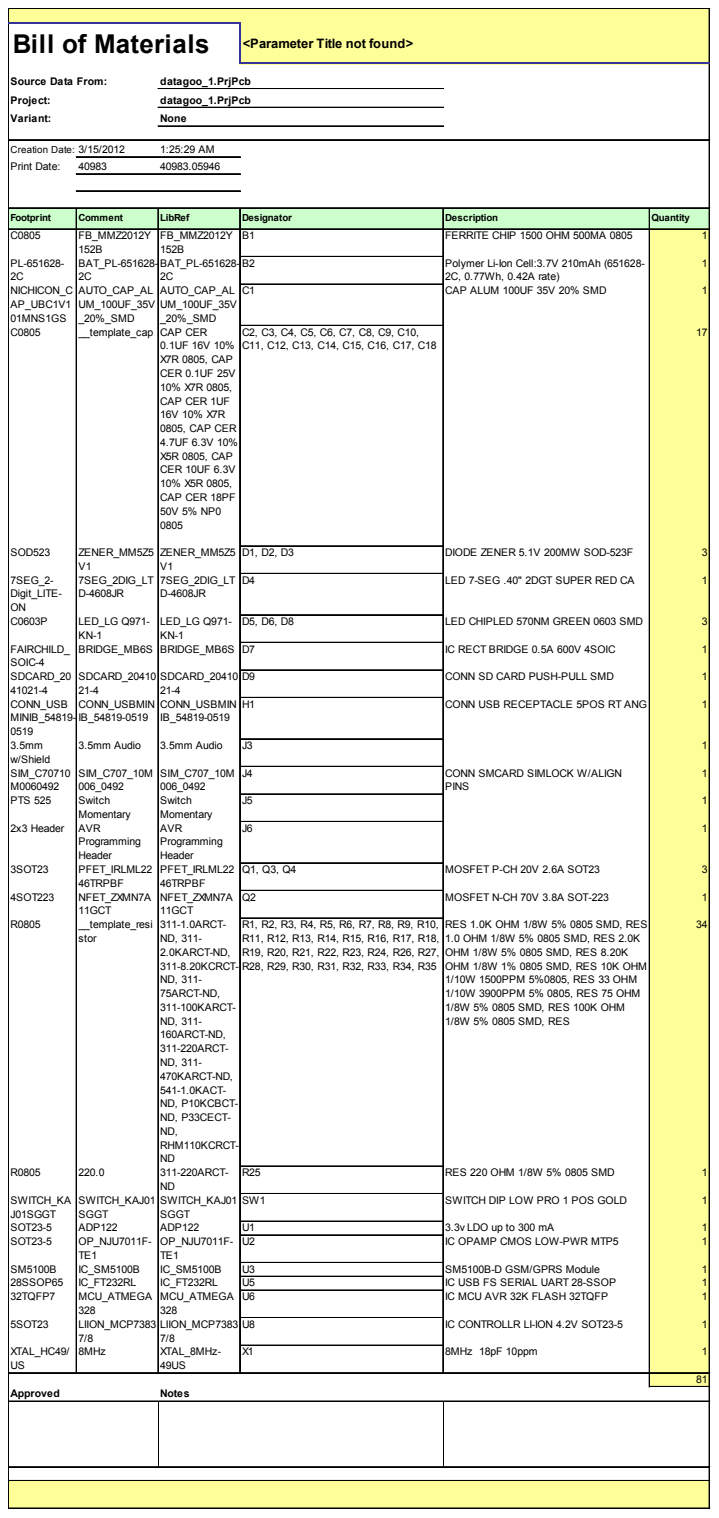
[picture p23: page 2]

RES 1.0K OHM 1/8W 5% 0805 SMD, RES
1.0 OHM 1/8W 5% 0805 SMD, RES 2.0K
OHM 1/8W 5% 0805 SMD, RES 8.20K
OHM 1/8W 1% 0805 SMD, RES 10K OHM
1/10W 1500PPM 5%0805, RES 33 OHM
1/10W 3900PPM 5% 0805, RES 75 OHM
1/8W 5% 0805 SMD, RES 100K OHM
1/8W 5% 0805 SMD, RES

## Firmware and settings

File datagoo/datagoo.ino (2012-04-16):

/*
DataGoo Firmware
Written by Ravi Sankar, Simon Ye, and Nathan Hall-Snyder
3/21/12

Description: This code is primarily designed for an open source energy-monitoring board, which
you can find details for at http://datagoo.readthedocs.org. However, it
can also run on a Cellular Shield from SparkFun Electronics, an SD Card Shield from Adafruit, and
an Arduino board. Details on those parts are also available at the readthedocs link.

An activated SIM card must be inserted into the SIM card holder on the board in order to use the device!
The device also requires a writeable SD card.

This sketch utilizes the following external libraries:
The EmonLib library written by Trystan Lea of OpenEnergyMonitor. The library can be downloaded at this URL:
https://github.com/openenergymonitor/EmonLib
The MsTimer2 library written by Javier Valencia. The library can be downloaded at this URL:
http://arduino.cc/playground/Main/MsTimer2
The JeeLib libraries written by the folks at JeeLabs.net. The libraries can be found from:
http://jeelabs.net/projects/cafe/wiki

and the following libraries provided with the Arduino platform:
The SoftwareSerial library: http://arduino.cc/en/Reference/SoftwareSerial
The SD library: http://arduino.cc/en/Reference/SD
The string library: http://arduino.cc/en/Reference/string
The Arduino Watchdog library 

This code is provided under the Creative Commons Attribution License. More information can be found here:
http://creativecommons.org/licenses/by/3.0/

(Use our code freely! Please just remember to give us credit where it's due. Thanks!)
*/

#include <Arduino.h>
#include <string.h>         //Used for string manipulations
#include <SD.h>             //SD card interface
#include <SoftwareSerial.h> //Include the SoftwareSerial library to send serial commands to the cellular module.
//#include <avr/wdt.h>      //this library would be used to enable auto-reset on device crashes
#include "EmonLib.h"        //energy calculations
#include "MsTimer2.h"       //required for the LED display
#include "LedDisplay.h"

#define sdPin 10
#define currentPin 0
#define voltPin 1

#define SERIAL_ON 0 //set this to 1 if you want serial printing on (for debug)
#define NUM_CAL_CONSTS 4 //the number of values in the calibration file


#define MILLIS_PER_DAY 86400000L
#define MILLIS_PER_HOUR 3600000L
#define TEXT_INTERVAL MILLIS_PER_DAY //ms: text every day
#define LOG_INTERVAL 60000 //ms: log every minute

SoftwareSerial cell(2,3);  //Create a 'fake' serial port. Pin 2 is the Rx pin, pin 3 is the Tx pin.

String mobileNumber = ""; //phone number to text status updates to
String inputString  = ""; //used to read input from the cell phone module
String timeString   = ""; //time string pulled from GSM module

int numTextsSent = 0;

float sumPower = 0.0;
int numPowerSamples = 0;

float calibrationConstants[NUM_CAL_CONSTS] = {238.5, 1.7, 75.71, 7}; //default calibration (volt, phase shift, current, gsm sband)
File logFile; //the file on the SD card that we are writing to
boolean sdAvailable = true;

unsigned long lastLoggedTime = 0; //in millis
unsigned long lastTextedTime = 0; //in millis
float lastVoltReading = 0; //to check for voltage drop
int lastPowerDisplayed = 0;

EnergyMonitor emon1; //used to do the actual energy calculations

//ISR(WDT_vect) { Sleepy::watchdogEvent(); } //watchdogs can be used to auto-restart the device on crash 

void parseCalibrationString(String calibrationString);
void startSMS(String mobileNumber);
void endSMS();
void sendText(String msg);
void cellReadLine();
void writeLogHeader(); 
void writeLogEntry(long time);
void setup();
void loop();

void setup()
{
  display_init();  // Initialize LED Display
  MsTimer2::set(10, display_switch_digit); // 10ms period on displaying digits
  MsTimer2::start();
  
  //Initialize serial ports for communication.
  Serial.begin(9600);
  cell.begin(9600);

  //Wait until network registration is complete (estimate 60s is sufficient)
  for (int i=60; i > 0; i--) {
    display_write(i); //count down every second on the display
    delay(1000);
  }

  //Initialize SD card
  pinMode(sdPin, OUTPUT);
  if (!SD.begin(sdPin)) {
    sdAvailable = false;
    if (SERIAL_ON) Serial.println("initialization failed!");
  }
  
  if (sdAvailable) {
    if (SERIAL_ON) Serial.println("initialization done.");
  
    //read the cell number to text off the SD card
    File cellFile = SD.open("cell.txt");
    if (cellFile) {
      while (cellFile.available()) {
        char c = (char) cellFile.read();
        if (c == '#') break;
        mobileNumber += c;
      }
      cellFile.close();
      mobileNumber.trim(); //get rid of whitespace
    } else {
      if (SERIAL_ON) Serial.println("Please make a file called CELL.TXT on the SD card containing the phone number you would like the power logger to text with daily stats");
    }
    
    //create the log file if necessary, with a header
    if (!SD.exists("log.csv")) {
      logFile = SD.open("log.csv", FILE_WRITE);
      if (logFile) writeLogHeader();
      logFile.close();
    }
    
    //setup power calibration numbers
    File calibrationFile = SD.open("cal.txt");
    String calibrationInput = "";
    if (calibrationFile) {
      while (calibrationFile.available()) {
        char c = (char) calibrationFile.read();
        if (c == '#') break;
        calibrationInput += c;
      }
      calibrationFile.close();
      calibrationInput.trim(); //get rid of whitespace
      parseCalibrationString(calibrationInput);
    }
  }

  //full list of SBANDs on page 127 of http://www.sparkfun.com/datasheets/Cellular%20Modules/CEL-09533-AT%20Command_V1%5B1%5D.0.0-1.pdf
  int sband = (int) calibrationConstants[3]; //default: 7
  cell.println("AT+SBAND=" + String(sband)); //for Guatemala, we think SBAND=7 should work (GSM850) but try SBAND=3 if it doesn't
  cell.println("AT+CMGF=1"); //Set GSM module on text (as opposed to voice) mode
  //cell.println("AT+CNMI=3,3,0,0"); //Set text messages to output to serial if you want to be able to use texts as input to DataGoo

  sendText("Hi, I'm DataGoo. Your number has been registered with me to receive updates on generator statistics.");

  // Voltage/Current calibration
  emon1.voltage(voltPin, calibrationConstants[0], calibrationConstants[1]);  // Voltage: input pin, volt_calibration, phase_shift
  emon1.current(currentPin, calibrationConstants[2]);       // Current: input pin, current_calibration
  
  display_write(0); //override the "88" that shows up on the display at startup
  emon1.calcVI(50,10000); //the very first reading after reset is always junk, so just take one reading and toss the result
}

void loop() {
  emon1.calcVI(50,10000); // measure 50 wavelengths, waiting for at most 10secs (10*1000ms)
  lastPowerDisplayed = (int) emon1.apparentPower / 1000;
  display_write(lastPowerDisplayed); //convert W to kW and display

  unsigned long now = millis();
  sumPower += emon1.apparentPower;
  numPowerSamples++;
  
  //check for and alert on voltage drops
  if ((emon1.Vrms < lastVoltReading / 2) && (lastVoltReading - emon1.Vrms > 10)) {
    String curVoltage = String((long)emon1.Vrms);
    sendText("There appears to be an error with the generator. Its voltage has dropped to " + curVoltage);
  }
  lastVoltReading = emon1.Vrms;

  //send a text on power readings
  if (now - lastTextedTime > TEXT_INTERVAL) {
    float powerAvg = sumPower / numPowerSamples * (now - lastTextedTime) / MILLIS_PER_HOUR;
    int truncatedAvg = (long) powerAvg;
    sendText("Energy generated (watt hours): " + String(truncatedAvg));
    numTextsSent++;
    sumPower = 0.0;
    numPowerSamples = 0;
    lastTextedTime = now;
  }
  //log power readings to the SD card
  if (now - lastLoggedTime > LOG_INTERVAL) {
    logFile = SD.open("log.csv", FILE_WRITE); //Open the log file on SD card
    if (logFile) {
      writeLogEntry(now);
      logFile.close();
      lastLoggedTime = now;
    }
  }

  //sample code to read texts to the device as input
  /*if (cell.available()) {
    cellReadLine();
    if (inputString.startsWith("datagootext")) {
      //dosomething
    }
    inputString = "";
  }*/
} 
  
/*-------------------------------------------------------------------
 * Helper Functions
 * ------------------------------------------------------------------ */

/* Converts the text from CAL.TXT into an array of 4 floats
 * (volt_calibration, phase_shift, current_calibration, and SBAND).
 * This last one is actually an int but is grouped her for convenience.
 */
void parseCalibrationString(String calibrationString) {
  calibrationString += '\n';
  int calStringLen = calibrationString.length();
  int i = 0;
  int j = 0;
  String calibrationConstantTemp = "";

  for (i=0; i < calStringLen; i++) {
    char calArray[15];
    char c = calibrationString[i]; //read a character at a time from the input string
    if (c == '\n') { //separate inputs based on newlines
      calibrationConstantTemp.toCharArray(calArray, 14);
      calibrationConstants[j] = atof(calArray); //and convert the strings to floats
      calibrationConstantTemp = "";
      j++;
      if (j >= NUM_CAL_CONSTS) return; //don't read more lines than expected
    }
    else if (c == ' ') { //ignore this whitespace
      continue;
    }
    else {
      calibrationConstantTemp += c;
    }
  } 
}

/* Converts the text from CELL.TXT into an array of up to 5 phone numbers
 * to send text updates to.
 *
 * Unfortunately, this code is buggy and we weren't able to figure out why.
 * Hopefully it will serve as a useful outline for the idea.
 */
//void parseMobileNumbers(String cellString) {
//  cellString += '\n';
//  int cellStringLen = cellString.length();
//  int i = 0;
//  int j = 0;
//  String temp = "";
//
//  //initialize the array
//  for (int k=0; k < MAX_PHONE_NUMS; k++) {
//    mobileNumbers[k] = "";
//  }
//
//  //now populate it
//  for (i=0; i < cellStringLen; i++) {
//    char c = cellString[i]; //read a character at a time from the input string
//    if (c == '\n') { //separate inputs based on newlines
//      mobileNumbers[j] += temp;
//      temp = "";
//      j++;
//      if (j >= MAX_PHONE_NUMS) return; //don't read more lines than expected
//    }
//    else if (c == ' ') { //ignore this whitespace
//      continue;
//    }
//    else {
//      temp += c;
//    }
//  }
//}

/* These functions basically print some magic strings to the cell module
 * to send texts. The information on what is expected is found here:
 * http://www.sparkfun.com/datasheets/CellularShield/SM5100B%20AT%20Command%20Set.pdf
 */
void startSMS(String mobileNumber)
{
  if (SERIAL_ON) Serial.println("starting SMS");
  cell.print("AT+CMGS=");
  cell.write(34); // ASCII equivalent of "
  cell.print(mobileNumber);
  cell.write(34);  // ASCII equivalent of "
  cell.println();
  delay(500); // give the module some thinking time
}
void endSMS()
{
  if (SERIAL_ON) Serial.println("ending SMS");
  cell.write(26);  // ASCII equivalent of Ctrl-Z
  delay(5000); //give the module some thinking time
}

/*
 * Use this function to text (over GSM) the string 'msg' to all the cell
 * phone numbers in mobileNumbers.
 *
 * startSMS and endSMS are helper functions for this function and shouldn't
 * be required by anything external (like the main loop)
 */
void sendText(String msg) {
  for (int i=5; i > 0; i--) { //a very short countdown to indicate text sending
    display_write(i);
    delay(200);
  }
  display_write(lastPowerDisplayed);
  startSMS(mobileNumber);
  cell.print(msg);
  endSMS();
}


/*
 * Repeatedly tries to read a character from the cell phone's serial output
 * until it sees an end-of-line character (\r) or the serial output overflows.
 * This allows us to deal with lines and responses to our commands, rather than
 * the individual characters that the Serial interface returns
 */
void cellReadLine() {
  long lastReadT = millis(); //keep track of when we started waiting for input

  while (1) {
    if (cell.available()) { //if there is available input from the cell
      char c = (char) cell.read(); //read it
      lastReadT = millis(); //and update our timer

      if (c == -1 || c == '\n') { //ignore these characters
        continue;
      }
      if (c == '\r' || cell.overflow()) { //and return in these cases
        return;
      }

      inputString += c; //add the character we just read to our string
    }

    //don't loop waiting for a complete line for more than a minute
    if (millis() - lastReadT > 60000) {
      return;
    }
  }
}

/* Write CSV header to SD card if the logFile is open
 */
void writeLogHeader() {
  logFile.print("Time (relative to startup)");
  logFile.print(",");
  logFile.print("Voltage");
  logFile.print(",");
  logFile.print("Current");
  logFile.print(",");
  logFile.print("Power");
  logFile.println();
}

/* Write CSV entry to SD card if the logFile is open
 */
void writeLogEntry(long time) {
  int dayNum = ((int) time/MILLIS_PER_DAY) + 1; //day 1 is the day of startup
  int secsOfDay = (long) (time % MILLIS_PER_DAY) / 1000; //number of seconds into this day
  String timeString = "day " + String(dayNum) + " and " + String(secsOfDay) + " seconds";
  logFile.print(timeString);
  logFile.print(",");
  logFile.print(emon1.Vrms);
  logFile.print(",");
  logFile.print(emon1.Irms);
  logFile.print(",");
  logFile.print(emon1.apparentPower);
  logFile.println();
}

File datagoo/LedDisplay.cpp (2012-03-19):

#include "LedDisplay.h"
#include <Arduino.h>
#include "binary.h"
typedef uint8_t boolean;
typedef uint8_t byte;

byte seven_seg_hex[10][3] = { {B00000000, B00000000, B00000100},  // = 0
                              {B00100000, B00000011, B00001100},  // = 1
                              {B10000000, B00000000, B00001000},  // = 2
                              {B00000000, B00000010, B00001000},  // = 3
                              {B00100000, B00000011, B00000000},  // = 4
                              {B01000000, B00000010, B00000000},  // = 5
                              {B01000000, B00000000, B00000000},  // = 6
                              {B00000000, B00000011, B00001100},  // = 7
                              {B00000000, B00000000, B00000000},  // = 8
                              {B00000000, B00000011, B00000000},  // = 9
                            };

volatile boolean seg_dig = 0;
volatile byte seg_onesD = 0;
volatile byte seg_onesB = 0;
volatile byte seg_onesC = 0;
volatile byte seg_tensD = 0;
volatile byte seg_tensB = 0;
volatile byte seg_tensC = 0;
const byte portD_bitmask = B11100000;
const byte portB_bitmask = B00000011;
const byte portC_bitmask = B00001100;
const byte portC_digits_bitmask = B00000011;

/*
 * Libraries
 */

//Expects a number between 0 and 9 to write to a digit

/*
 * Function that writes a number (0-99) to the seven segment display.
 */
void display_write(int digit){
  
  while(digit >= 100) digit = digit/10;
    
  //Turn on ALL the digits
  seg_onesD = seven_seg_hex[digit % 10][0];
  seg_onesB = seven_seg_hex[digit % 10][1];
  seg_onesC = seven_seg_hex[digit % 10][2];
  seg_tensD = seven_seg_hex[digit / 10][0];
  seg_tensB = seven_seg_hex[digit / 10][1];
  seg_tensC = seven_seg_hex[digit / 10][2];
}

//Inits the pins for the seven segment display. Must be called in setup()
void display_init(){
  pinMode(A4, OUTPUT); //Digit Two
  pinMode(A5, OUTPUT); //Digit One
  pinMode(5, OUTPUT); //Segment A
  pinMode(6, OUTPUT); //Segment B
  pinMode(7, OUTPUT); //Segment C
  pinMode(8, OUTPUT); //Segment D
  pinMode(9, OUTPUT); //Segment E
  pinMode(A3, OUTPUT); //Segment F
  pinMode(A2, OUTPUT); //Segment G

  //Turn off the digits

  digitalWrite(5, HIGH); //A
  digitalWrite(6, HIGH); //B
  digitalWrite(7, HIGH); //C
  digitalWrite(8, HIGH); //D
  digitalWrite(9, HIGH); //E
  digitalWrite(A3, HIGH); //F
  digitalWrite(A2, HIGH); //G
 
  digitalWrite(A5, LOW);
  digitalWrite(A4, HIGH);
  seg_dig = 1;
}

void display_switch_digit(){
  PORTC = PORTC ^ B00110000; //Toggle the characters
  if(seg_dig){
    PORTD = (PORTD & ~portD_bitmask) | (seg_onesD);
    PORTB = (PORTB & ~portB_bitmask) | (seg_onesB);
    PORTC = (PORTC & ~portC_bitmask) | (seg_onesC);
    seg_dig = 0;
  } else {
    PORTD = (PORTD & ~portD_bitmask) | (seg_tensD);
    PORTB = (PORTB & ~portB_bitmask) | (seg_tensB);
    PORTC = (PORTC & ~portC_bitmask) | (seg_tensC);
    seg_dig = 1;
  }
}

/* Test sketch
 *
 * void setup() {
 *   seg_init();
 *   MsTimer2::set(10, seg_swap); // 500ms period
 *   MsTimer2::start();
 * }
 */

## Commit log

2012-02-20 Text sending framework in place
2012-03-05 Adding sketch for LED Display control
2012-03-06 Fixed up LedDisplay library.
    [LedDisplay.cpp]
2012-03-06 Fix up LedDisplay.h
2012-03-19 Code changes to log power measurements to SD card
2012-03-19 Updated documentation to reflect Google Site.
    [Cover.STEP, Cover.STL, Lower Body.STEP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]
2012-03-19 Work on quickstart and calibration reading from SD.
    [components.csv]
2012-03-21 Added pictures of attching datagoo voltage terminals.
2012-03-21 Update frontpage transparent cad image.
2012-03-21 Add case exploded view.
2012-03-21 Added real life photos and to landing page.
2012-03-21 Code changes to text energy usage rather than power and for prettier text countdowns on the LCD
